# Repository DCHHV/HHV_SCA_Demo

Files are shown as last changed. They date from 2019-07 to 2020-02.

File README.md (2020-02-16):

# DEF CON Hardware Hacking Village Side Channel Attack Demo
This demo focuses on teaching and exploiting a simple timing attack vulnerable set up. It is a hardware device that consists of a PIC12F1572 (Enhanced Mid-range), 4 tactile buttons, LED indicators, an FTDI USB serial interface, and a connection for a logic analyzer (specifically a USBee AX PRO which the HHV has a small stock of). The demo is self-guided, that is, the serial interface provides instructions on each stage of the demo.

## About
The demo consists of 4 stages that become increasingly difficult. Each stage requires the user to identify a valid PIN for that stage. The PIN is a 4 digit, 4 value number; this provides 256 combinations. Due to the low complexity and lack of timeout penalty, brute forcing a PIN for each stage is reasonably possible but highly discouraged since the intent is to learn about side-channel attacks.

There are two LEDs, a red and a green, that flicker when the PIN is being input. The green LED turns on when a button is pressed, and off when it is released. Depending on the stage, once the full PIN is input, the red LED will flash if the pin was incorrect, or the green LED will turn solid for a few seconds if it was correct. The USB serial interface also has a red and green LED to indicate serial activity.

The digits of the PIN are connected to a single analog input of the PIC. Between the switches, a resistor ladder is set up. This allows for a consistent and unique analog voltage value for each digit. The analog input is polled at roughly 8 ms from the PIC (this timing has no bearing on the SCA demo or its vulnerabilities).

The red and green LEDs for the PIN input are connected to a 2x5 0.1" female header. A USBee AX PRO can be directly connected to this input. The LEDs are then connected to D0 and D1 of the logic analyzer. This logic analyzer is compatible with `sigrok`/`pulseview`, it is not a Saleae clone. Any other 3.3 V compatible logic analyzers can be used instead; it was highly convenient to use this pinout as the HHV has a stock of the USBee logic analyzers.

Note that we have observed that some models of Saleae clones actually work better in `pulseview` than the official Logic software. This may be due to a number of reasons, but it was found that in the Logic software both for Windows and Linux, a Saleae clone would often fail to run at 16 MHz. This failure was followed up with a comment to lower the sample rate and try again. Under `pulseview` for both Windows and Linux however, this device performed at the 16 MHz sample rate quite reliably. The USBee AX PRO is not a Saleae clone; this observervation is provided as a reference for using other logic analyzers.

A full breakdown of each stage, how the vulnerability works, step by step instructions, and proper mitigation techniques for this specific setup, are available in `docs/README.md`

## Setup
There is a specific order to the following steps, this is due to `pulseview` recognizing the FTDI device and attempting to utilize it as a logic analyzer interface. Doing this in any other order is possible but it becomes a hassle as `pulseview` tries to consume the USB serial device, even if it is already open in some cases.

1. Connect the USBee AX PRO to the host computer
2. Open `pulseview`. The tool should automatically detect and initialize the logic analyzer, if not, it can be manually set up by scanning for 'fx2lafw' devices. Note that on Linux based systems, there is a separate firmware package for the 'fx2lafw' firmware files.
3. Connect the FTDI USB serial cable (if this is connected before `pulseview` is started, then `pulseview` may try to claim the FTDI device)
4. Open a serial terminal to the just created USB terminal at 9600 baud, 8n1.
5. Press "RESET" button on the HHV SCA Demo board; text should appear on the terminal

## Build your own
All of the PCB sources for EagleCAD are available in the `eagle/` directory. The Gerber files are available in the `eagle/out/` directory and are named directly for use with OSHPark. Simply zip up the files and upload them. The Gerber files are also compatible with pretty much every PCB manufacturer as-is. A full BOM is also in the `eagle/` directory.

The PIC _can_ be programmed via the on-board ICSP header by connecting a PICKit device which supports PIC12F1572. However, we do not recommend connecting directly to this and instead recommend programming the microcontroller out of circuit. Due to conflicting driving signals, there are two marked pads that must be cut for ICSP operation. These must be bridged back together for normal operation.

The `HHV_SCA_Demo-production.hex` file can be directly written to the PIC12F1572.

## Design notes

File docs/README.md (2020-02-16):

# Writeup
**NOTE: This document contains spoilers! While the PIN for each stage is unique every time, this document discusses each stage in detail and how to derive its PIN. Do not proceed if you do not want hints.**

The goal of each stage is to work out the correct PIN. Each stage has a unique 4 digit, 4 value PIN number that is randomly generated each reset of the whole device. As the player progresses through the stages they become increasingly difficult and more subtle.

The following sections describe each stage of the demo; how to exploit the vulnerability, why the vulnerability exists, and eventually how to better mitigate against side-channel attacks. The information here is intended for educational purposes.

Each stage will also output text on the serial terminal. That text is not repeated here as it is simply a description of the stage as well as hinting at how the vulnerability is possible. The text below on each stage provides a more in-depth guide on the stages themselves.

## Stage 0
This stage is meant to be a quick introduction in to how the keyspace can be reduced. Normally, the 4 digit 4 value PIN has 4^4 (256) values. However, the keyspace reduction that is possible is due to the various side-channel vulnerabilities reduces each stage to no more than 4+4+4+4 (16) attempts.

Stage 0 wants a 4 digit PIN, however, it will immediately show a PIN failure if the entered digit is incorrect. For example, if the expected PIN is `0231`:

1. Pressing `0` will result in the green LED turning on when the button is depressed, and the green LED turning off again when the button is released. This means the first digit was correct.
2. Pressing `1` next will also result in the green LED turning on when the button is depressed and back off again when it is released. However, since the second digit of the expected PIN is `2` and we entered a `1`, the red LED will rapidly blink indicating a failure of the PIN input. The device will then go back to waiting for the first PIN digit again.

These two steps indicated to us that `0` is the first digit, and `1` is _NOT_ the second digit. This alone has reduced our keyspace to 0+3+4+4 (11) more attempts as we know the first digit and have eliminated one of the possible second digits. There are 3 more possibilities for the second digit, and it may take 3 attempts to find it if our luck is bad.

This process is repeated until each digit value is found. Once all four correct digits are entered, the green LED will remain solid for roughly 2 seconds indicating success. The next stage is started and text will be output on the terminal to reflect that.

## Stage 1
This stage implements a very common comparison routine to check the input PIN against the expected PIN. This comparison looks at each digit, in order, and compares the input against the expected. If any digit is wrong, the comparison fails immediately. This means that, for each correct digit input, this compare loop takes longer. The exact code implemented is reflected below, it is pulled from `HHV_SCA_Demo.X/main.c`

```C
uint8_t kp_compare()
{
...
	switch(stage) {
	  ...
	  case 1:
		for (i = 0; i < pincnt; i++) {
			if (pin_input[i] != pin[i]) return 0;
		}
	  ...
}
```

When `kp_compare()` is called, and the Demo is currently on Stage 1, the code will iterate through the input PIN and the expected PIN, returning instantly if there is a failure. This creates a difference in execution time when no digits are correct versus the 1st digit is correct, or the first 2 digits are correct, etc.

This is where the LEDs and the logic analyzer connected to them start to become important. Once the 4th digit button is released the green LED turns off to indicate that the button was released. After that, this `kp_compare()` function is called, which takes a variable amount of time to execute depending on how many digits are correct. Once this function is completed, either the green LED turns on to indicate a success or the red LED flashes rapidly to indicate the input PIN was incorrect.

By using the logic analyzer and `pulseview`, this time can be easily measured. The recommended settings are a 12 MHz sample rate, with 500 M Samples. This will result in about 40 seconds of capture time. Additionally, a soft trigger can be set up on the falling edge of D0.

For example, if the expected PIN is `1330`:

1. Start the capture in `pulseview`
2. Enter the PIN `0000`
3. Stop the capture in `pulseview`
4. Zoom in to the very small area between the last rising edge of D1 (the green LED turning off), and the first falling edge of D0 (the red LED turning on to indicate an incorrect input). This area is very small and is only a few hundred microseconds in length!
5. Set up the timing markers on these two edges and note the time between them.
6. Repeat steps 1 through 5 with the PIN `1111`

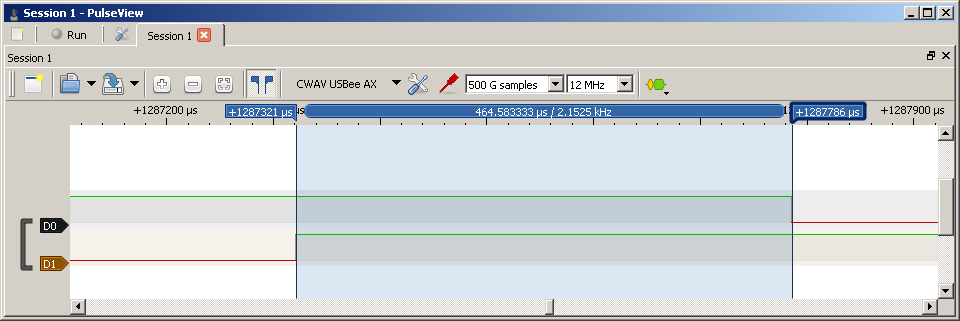
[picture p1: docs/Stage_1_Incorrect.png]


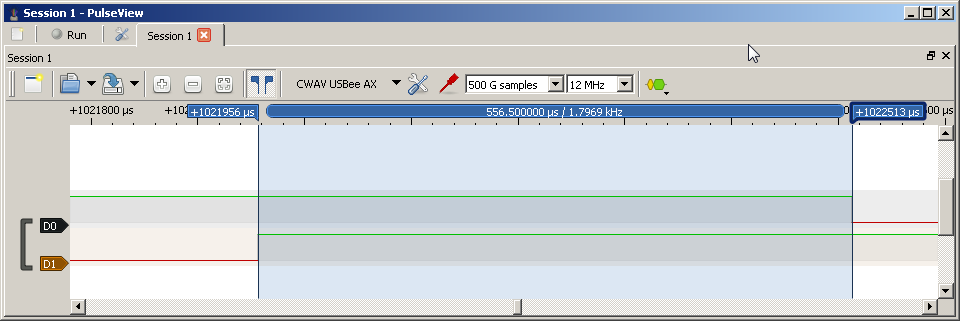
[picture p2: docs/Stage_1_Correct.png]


Notice that the time for a PIN of `1111` takes ~100 μs longer than the PIN of `0000`! This indicates to us that the first digit of the PIN is indeed a `1`. This process is then repeated for each digit position. For example, the next PIN attempt would be `1000` and then `1222` (`1111` was already tested!) and `1333`. One of those will yield a similar timing difference (~100 μs longer) which will indicate the correct 2nd digit; and so on. Note that once the first three digits are resolved, the last one can simply be brute forced in this case. Further testing of the timing will yield no additional results as either the guessed digit was correct (which would complete the stage) or incorrect (which gives no additional information about what the correct digit is).

## Stage 2
Stage 2 adds a little more complexity and subtlety. At the surface it is a naive attempt to mitigate a side-channel attack. Unlike Stage 1, this Stage will not fail the check with a single incorrect digit. Stage 2 will compare each digit of the input and expected PIN and will clear a variable if there is a mismatch. Once all digits are checked, that variable is returned from the function. If the variable is non-zero then the input PIN was correct, if it is zero (that variable was cleared due to an incorrect digit) then any number of digits were incorrect.

The difference here is that when a digit is incorrect an extra step occurs; the clearing of the variable. This clear happens unconditionally, so it happens for every incorrect digit. The exact code used for this is reflected below, it is pulled from `HHV_SCA_Demo.X/main.c`

```C
uint8_t kp_compare()
{
...
	switch(stage) {
	  ...
	  case 2:
		ret = 1;
		for (i = 0; i < pincnt; i++) {
			if (pin_input[i] != pin[i]) {
				ret = 0;
				asm("nop");
			}
		}
	  ...
}
```

_Note: As indicated in the comments in `main.c`, the PIC architecture makes this specific scenario difficult to achieve. Without the `nop` instruction, the emitted code by the xc8 compiler is correctly balanced; it takes the same number of instructions for a matching and non-matching digit. The `nop` forces this extra instruction in this case. Other architectures and/or compilers optimized for execution speed rather than code size may output unbalanced code around this if() statement without the additional `nop` instruction. This highlights that not all code is perfectly portable. This code without the `nop` instruction might be balanced on this PIC, but when moved to a different microcontroller with a different compiler, that code may open up a vulnerability to SCA exploitation._

The next important bit of information involves the PIC itself. The PIC12F1572 that is handling all of this, is running at a clock speed of 1 MHz. This specific series of devices has 4 clocks per every instruction executed. This means that the instructions are executed at a rate of 250 kHz, or one instruction every 4 μs. Note that some instructions take multiple instruction cycles; but for the purpose of this stage each path has a 1 instruction difference.

To bring it all together, for every incorrect digit of the input PIN, the PIC runs one additional instruction compared to if the digit were correct. Every incorrect digit results in a 4 μs increase in execution time. When looking at the LEDs in the logic analyzer, the difference between the last rising edge of D1 and the first falling edge of D0 increases 4 μs for each digit that is incorrect. This specific implementation will essentially tell you how many digits you have correct or incorrect, but not which ones. It can be compared to a game of [Mastermind (external link)](https://en.wikipedia.org/wiki/Mastermind_(board_game))

For example, with a PIN of \[REDACTED\]

1. Start capture in `pulseview`
2. Enter PIN `0000`
3. Stop capture in `pulseview`
4. Zoom in to the very small area between the last rising edge of D1 (the green LED turning off), and the first falling edge of D0 (the red LED turning on to indicate an incorrect input). This area is very small and is only a few hundred microseconds in length!
5. Set up the timing markers on these two edges and note the time between them.
6. Repeat steps 1 through 5 with the PIN `1111`, `2222`, and `3333`
7. Some logic and reasoning needs to be used here. With the above PINs, we gathered the following details:

   `0000` Took 841 μs
   `1111` Took 841 μs
   `2222` Took 837 μs
   `3333` Took 845 μs

   Note that `3333` took the longest, with at least two more incorrect digits than `2222`. This tells us that there are likely multiple `2`s in the final PIN, and likely no `3`s. But in order for us to continue, we need to eliminate one of the variables by resolving one of the digits. Let's repeat steps 1 through 5 with the following combinations.

   `2000` Took 841 μs
   `0200` Took 845 μs

   Stopping there, we see the difference between `0000` (see above) and `0200` is that `0200` is one instruction longer, meaning the `0` in the second place was correct, and replacing it with a `2` made that digit incorrect. We have just found our first digit, `x0xx`

   `0020` Took 837 μs

    Stopping there again, we see that changing the third place digit from a `0` to a `2` caused it to decrease in time and therefore meaning it is correct. We have now found our second digit, `x02x`

   `0022` Took 833 μs

   This is our last needed test. Moving the fourth digit from a `0` to a `2` yet again decreased the comparison time. This indicates that 2 is indeed the final digit. We have found three of the digits, `x022`.
   
   But actually, we already know the final digit! Above, it was noted that `0000` and `1111` took the same amount of time. This means that both of them have the same number of correct and incorrect digits. If `x022` is the correct PIN, then the PINs `0000` and `1111` have at least the final two digits incorrect meaning that each of them also have a correct and incorrect digit. If the final PIN is `x022` then the correct digit in `1111` would be the first place digit, meaning the full PIN is `1022`.

It is important to note that this evaluation process is not the same every time. There are seeds where the first four samples above will all take the same amount of time! With that, you can know that each of them has a single correct digit, and the final PIN has no repeating values. A lot of side-channel attacks require reasoning and deduction in order to understand how the whole system works together. Also note that as in Stage 1, it would be possible to brute force the missing first digit. We just happened to have enough information already in order to work out what it was.

## Stage 3
This stage, to the best of my abilities, is immune from a side-channel timing attack. It is difficult to prove something as "secure" unfortunately. But, the comparison function for this stage is hand-tuned assembly code that has been shown to be the same amount of instructions for each matching or non-matching PIN digit. This stage builds on the concept of the previous Stage. Each digit of the input PIN and expected PIN are compared one by one. For each correct digit the next iteration of the loop is run. For each incorrect digit a variable is incremented. However the paths for correct and incorrect digits take the same amount of instruction cycles. Meaning that no matter how many digits are correct or incorrect, the same amount of time elapses in the comparison function, and no data is leaked out about the expected PIN. After the comparison loop, the variable's value is examined. If the variable is `0`, then none of the digits were incorrect. If the variable is any other value, then some number of digits were incorrect.

Additionally, interrupts are disabled before the call to `kp_compare()` (this happens on every stage anyway). 

This takes place over two functions, `kp_compare()` as all of the other Stages have used, which makes a call to an assembly function `_proper_compare`. The important parts of these are outlined below, taken directly from `HHV_SCA_Demo.X/main.c` and `HHV_SCA_Demo.X/proper_compare.s`

```C
uint8_t kp_compare()
{
...
	switch(stage) {
	  ...
	  case 3:
		if (proper_compare() != 0) ret = 0;
		break;
	  ...
}
```
```
_proper_compare:

    CLRF    _cmp
    MOVLW   3;
    MOVWF   _loop;

stage_3_loop:
    /* Load the address of pin_input+3 in to FSR0 */
    MOVLW   low _pin_input
    ADDWF   _loop, W
    MOVWF   FSR0L
    CLRF    FSR0H

    /* Load the address of pin+3 in to FS10 */
    MOVLW   low _pin
    ADDWF   _loop, W
    MOVWF   FSR1L
    CLRF    FSR1H

    /* Compare the two values via XOR. Z flag is set when they are equal */
    MOVF    INDF0, W;
    XORWF   INDF1, W;

    /* Start critical section */
    BTFSS   STATUS, 2;          // 2 cycles if Zero is set, 1 if not. Bit 2 is Z
    INCF    _cmp, F;            // 1 cycle.
    /* End critical section */

check_loop:                     //From BTFSS, both paths take 2 cycles to here.
    CLRW;
    XORWF   _loop, W;
    BTFSC   STATUS, 2;          //2 cycles if true, 1 if false. Bit 2 is Z
    GOTO    end_loop;

    DECF    _loop, F;
    GOTO    stage_3_loop;
...
```

Despite all of that however, Stage 3 is weak and the PIN can be derived through other means.

When starting up the demo, the intro screen on the terminal talks about setup and other background information and asks you to press "Enter" to continue. In the background, a timer is running from the moment the PIC is released from internal reset. It is when "Enter" is pressed on the keyboard that this 8-bit timer is sampled and used as a seed value for all of the expected PINs. This seed is also printed in such a way that it is hidden on most serial terminals.

From this seed, a PRNG using a Galois Linear Feedback Shift Register is used to transform it to the next step. The first transformation is used for Stage 0, it is transformed again for Stage 1, etc. Each stage only transforms the number one time. However, since the seed and each transformation of the PRNG is only 8-bits, it is a fairly weak PRNG that allows it to be easily discovered.

The PRNG transformation happens with the function below, taken directly from `HHV_SCA_Demo.X/main.c`

```C
void generate_pin(void)
{
	uint8_t seed_copy, i;
	seed = seed >> 1;
	if (CARRY) seed ^= 0xB8;
	seed_copy = seed;
	for (i = 3; i != 0; i--) {
		pin[i] = seed_copy & 0x3;
		seed_copy >>= 2;
	}
	pin[0] = seed_copy & 0x3;
}
```

Each transformation shifts the value one to the right. If the least significant bit before the shift was a `1`, then the whole value is XORed against the value 0xB8. Then, each pair of bits is used to represent 1 digit. The first digit is represented by seed bits 7:6, the second is seed bits 5:4, etc. Since each pair of bits can represent a value of 0 through 3, they directly correlate to the values that can be input.

Often it is possible to gather the seed and each PIN from all prior stages and reverse engineer how the PRNG transforms for each stage. However it is also possible that multiple run-throughs of the stages are necessary to gather all of the information. Having a seed that has both the right shift by itself, as well as the XOR operation occur throughout the transformations will allow one to see exactly what is going on. There are some seeds that will only result in a right shift for every transformation through the Stages, and other seeds that will only result in the shift and XOR for every transformation through the Stages. It is these seeds that will require multiple run-throughs of the Demo.

Once the transformation process is understood however, it is possible to see the seed and derive every single PIN for all 4 Stages.

## Mitigations
In this application, only time was used as a side-channel attack vector. There are many other sections of side-channel data that can be used in similar attacks. Some of the other common ones are power monitoring, and electromagnetic radiation monitoring. All of the Stages of this demo may be susceptible to other types of attacks. If you are able to demonstrate another type of analysis on this device, we would love to hear about it!

The process used in Stage 3 is likely the most robust. However, it does depend on a completely deterministic processor and firmware so that each code path can be properly tuned. And since the interrupts are disabled during the compare, nothing can be used to stall or interfere with the compare functions. Systems with pipelines and/or other optimizations to speed up execution at the cost of determinism may not be able to implement such a simple system without a performance hit.

To the best of my knowledge, there are currently no blanket rules or guidelines to follow to reduce the attack surface and mitigate any kind of side-channel attacks. Each application must determine the best security and best course of action to accomplish this.

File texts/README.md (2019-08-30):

# Texts
Text strings used in the Demo. See `tools/README.md`, `tools/string_packer.c`, and `HHV_SCA_Demo.X/main.c` for information on how these texts are formatted and used.

The `./build-asm.sh` script is provided as a helper function to quickly rebuild the `strings.s` source file used during final assembly of the project

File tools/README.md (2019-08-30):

# Tools

## Building
Simply run `make` to build all of the tools here. They are simple C programs that rely on no external libraries.

## pin\_predictor
For testing purposes, the `pin_predictor` tool can be used to output every combination of every possible seed. Useful for jumping through to specific stages, verifying the PRNG transformation works as expected, etc.

It is just run with `./pin_predictor` and will output the 4 PIN associated with each stage for every seed from 0x00 through 0xFF. Note that seed 0x00 is invalid during runtime of the Demo itself. All four of the stages have the same pin of `0000`.

## string\_packer
In order to fit all of the text in to the PIC that is in there the characters all needed to be packed two to a single word. The PIC12F1572 uses 14-bit instruction words. With 7-bit ASCII this allows for storing two characters in each instruction word. The full 14-bit value of the instruction word can be arbitrarily loaded with assembly directives. However, when using strings in C, they are packed as a single character per word.

This tool was created to take a listing of plaintext via stdin (all of which are maintained in the `texts/` directory) and output very specifically formatted text that can be added to the project as an assembly include. The expected input format is:

```
<name_of_array>
Text to put in.\r\n
...
```

And the tool will output via stdout:

```
PSECT strings,class=CODE,local,delta=2
GLOBAL _<name_of_array>
_<name_of_array>:
DW      0x... ; "XX"
...
```

The \<name\_of\_array\> names are critical as they must align with expected names in the C sources.

The `string_packer` tool will accept the most common escape sequences, `\n`, `\r`, `\t`, and `\\`. If an invalid escape is used, the program will fail an spit out the byte that it tripped on.

In the assembly output, the two represented characters will be appended to the line as a comment, for example:

`DW      0x2A68 ; "Th"`

Since all strings must end on a `\0` byte, `string_packer` adds either a single 0x00 to the lower byte of an instruction word, or a full instruction word of 0x0000. Adding a `\0` at the end of the plaintext is not needed and will cause errors. Example output of this process:

```
...
DW      0x2E80 ; "]\0"
...
DW      0x0000 ; "\0\0"
...
```

The firmware on the PIC has a decode function to be able to print these packed strings. Since the `string_packer` added `\0` bytes at the end of each string, the print function in the PIC will read byte by byte until it encounters a `\0` byte like a normal string print function.

The `string_packer` tool can be run with `./string_packer < textfile.txt >> strings.s`. The order of the text files to be processed does not matter, but it is most logical to keep them in order that they are printed.

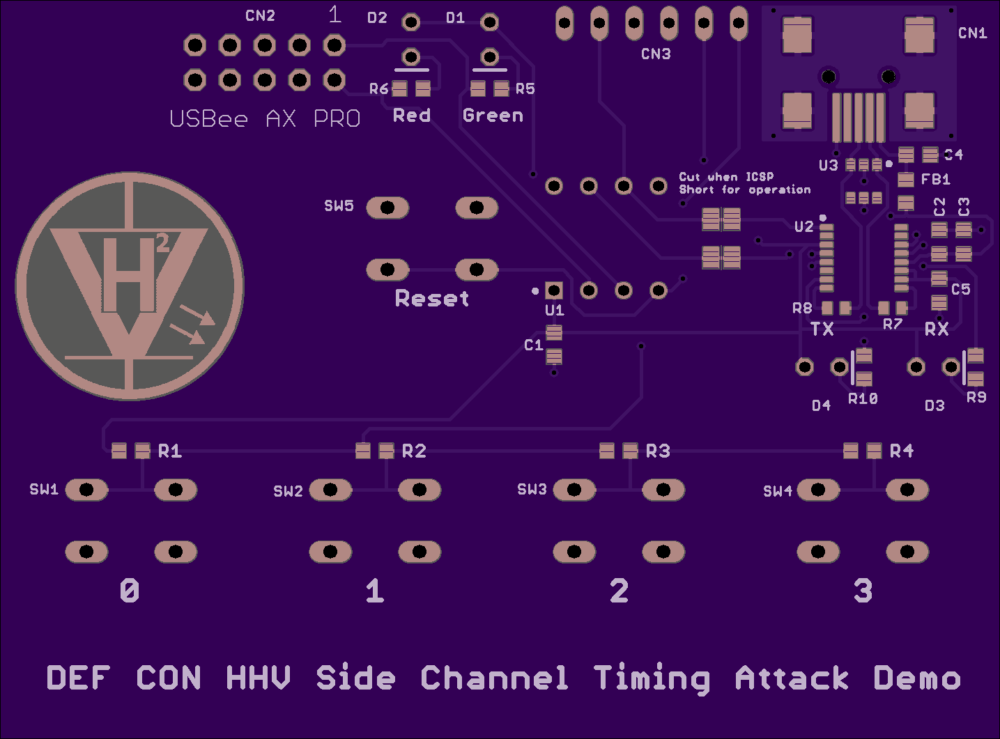
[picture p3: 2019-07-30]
docs/OSHPark-top.png

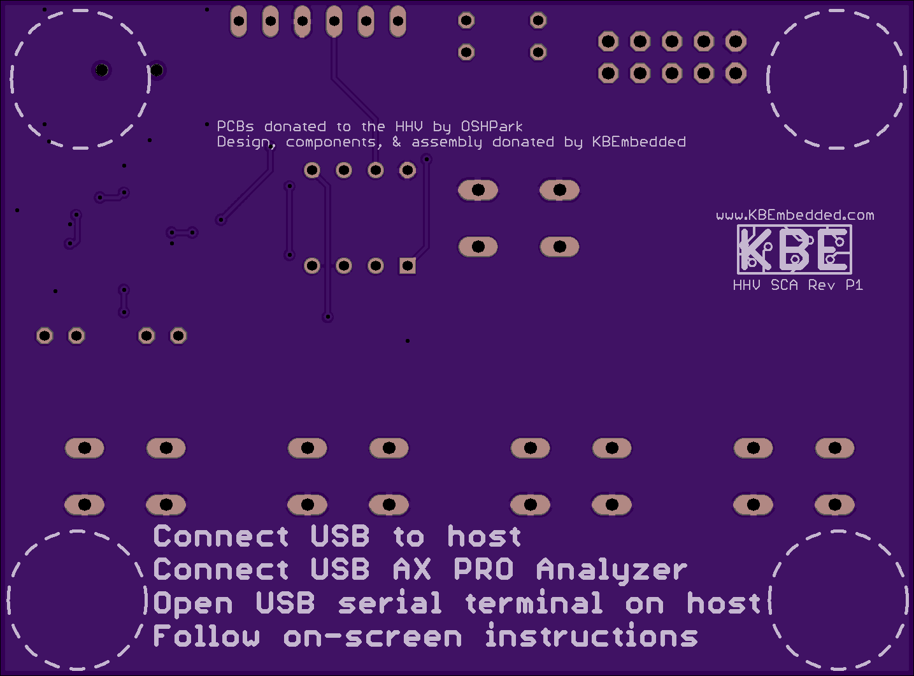
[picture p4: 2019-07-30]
docs/OSHPark-bottom.png

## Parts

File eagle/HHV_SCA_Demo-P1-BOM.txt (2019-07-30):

Qty Value        Device       Package      Parts                   Description                
1                R-EU_R0603   R0603        FB1                     FERRITE BEAD
2   27           R-US_R0402   R0402        R7, R8                  RESISTOR
4   100          R-US_R0603   R0603        R5, R6, R9, R10         RESISTOR
4   10k          R-US_R0603   R0603        R1, R2, R3, R4          RESISTOR
1   10nF         C-EUC0603K   C0603K       C4                      CAPACITOR
3   .1uF         C-EUC0603K   C0603K       C1, C2, C5              CAPACITOR
1   4.7uF        C-EUC0603K   C0603K       C3                      CAPACITOR
1   AOZ8105CI    AOZ8105CI    SOT23-6L     U3                      TVS
1                FE06-1       FE06         CN3                     FEMALE HEADER              
1                MA05-2       MA05-2       CN2                     PIN HEADER                 
1   FT230XS      FT230XS      SSOP16       U2                      USB to BASIC UART IC       
1   MINIUSB-SMD  MINIUSB-SMD  MINIUSB-SMD  CN1                     EDAC 690-005-299-043       
1   PIC12F1572   PIC12F1571   DIL8         U1                      PIC12F1571/2               
2   RED          LED3MM       LED3MM       D2, D3                  LED                        
2   GRN          LED3MM       LED3MM       D1, D4                  LED                        
5                10-XX        B3F-10XX     SW1, SW2, SW3, SW4, SW5 OMRON SWITCH

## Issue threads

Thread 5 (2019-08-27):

Text: Change recommended settings to 12 MHz @ 500 M samples

kbembedded, 2019-08-27:
Some of the USBee AX PROs have issues running at 16 MHz. It seems to be pretty dependent on the computer, the device, and even the cable. In testing, 12 MHz has been very reliable in all situations.

The 12 MHz @ 500 M samples takes about 500 MB of RAM

kbembedded, 2020-02-16:
Fixed in 0e4efee7c25362291c2eec0b00dc4f5ef78d1afe

Closed 2020-02-16.

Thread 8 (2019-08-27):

Rewrite Stage 2 code to be correct no matter the compiler

kbembedded, 2019-08-27:
Currently, with xc8 2.05 compiler, it accidentally optimizes the code to have balanced code paths for both correct and incorrect digits.

This likely needs to move to an assembly routine so that it can be properly tuned so that is intentionally unbalanced and agnostic of any future compiler changes.

kbembedded, 2020-02-16:
Not easily possible with PIC architecture without going out of the way to write weird code. Left the asm `nop` in place in C and added documentation about it.

Closed 2020-02-16.

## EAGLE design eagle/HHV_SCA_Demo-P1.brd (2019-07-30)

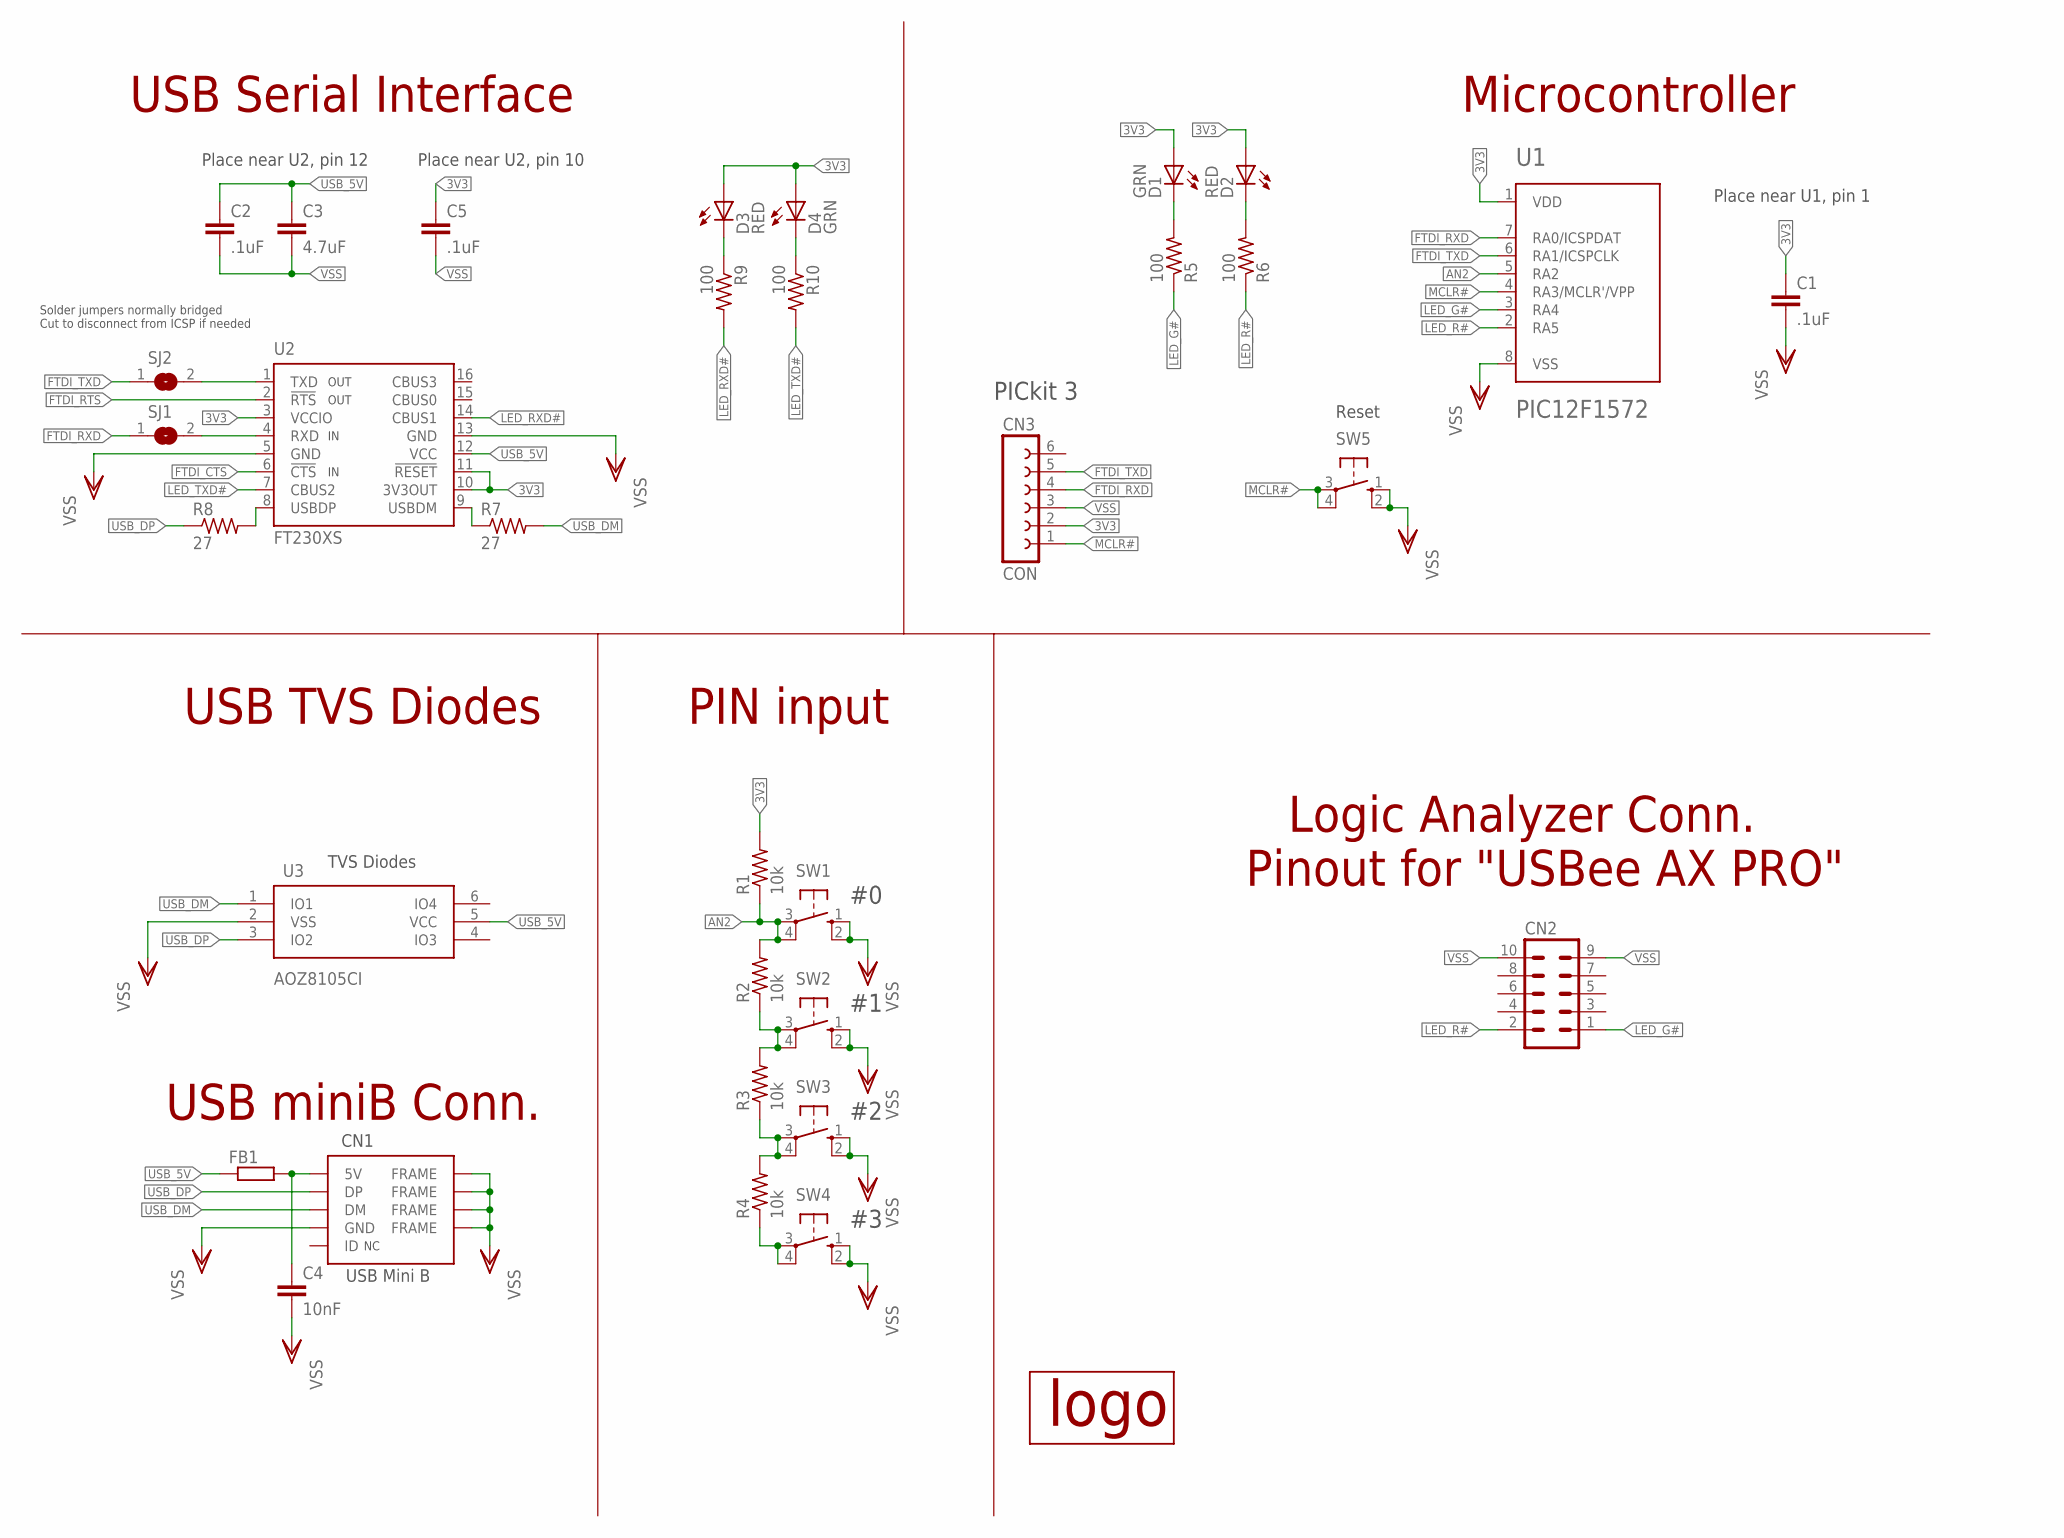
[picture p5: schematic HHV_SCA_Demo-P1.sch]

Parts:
C1, C2, C5: .1uF; C0603K
C3: 4.7uF; C0603K
C4: 10nF; C0603K
CN1: MINIUSB-SMD
CN2: MA05-2
CN3: CON; FE06
D1, D4: GRN; LED3MM
D2, D3: RED; LED3MM
FB1: R-EU_R0603; R0603
R1, R2, R3, R4: 10k; R0603
R5, R6, R9, R10: 100; R0603
R7, R8: 27; R0402
SJ1, SJ2: SJ
SW1, SW2, SW3, SW4, SW5: 10-XX; B3F-10XX
U1: PIC12F1572; DIL8
U2: FT230XS; SSOP16
U3: AOZ8105CI; SOT23-6L
U$1: KBELOGO-SILK

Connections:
3V3: C1.1, C5.1, CN3.2, D1.A, D2.A, D3.A, D4.A, R1.2, U1.1 (VDD), U2.3 (VCCIO), U2.10 (3V3OUT), U2.11 (!RESET)
AN2: R1.1, R2.2, SW1.3, SW1.4 (P1), U1.5 (RA2)
FTDI_CTS: U2.6 (!CTS)
FTDI_RTS: U2.2 (!RTS)
FTDI_RXD: CN3.4, SJ1.1, U1.7 (RA0/ICSPDAT)
FTDI_TXD: CN3.5, SJ2.1, U1.6 (RA1/ICSPCLK)
LED_G#: CN2.1, R5.1, U1.3 (RA4)
LED_R#: CN2.2, R6.1, U1.2 (RA5)
LED_RXD#: R9.2, U2.14 (CBUS1)
LED_TXD#: R10.2, U2.7 (CBUS2)
MCLR#: CN3.1, SW5.3, SW5.4 (P1), U1.4 (RA3/MCLR'/VPP)
unnamed: R4.1, SW4.3, SW4.4 (P1)
unnamed: R3.1, R4.2, SW3.3, SW3.4 (P1)
unnamed: D2.K (C), R6.2
unnamed: R7.1, U2.9 (USBDM)
unnamed: R2.1, R3.2, SW2.3, SW2.4 (P1)
unnamed: R8.2, U2.8 (USBDP)
unnamed: D1.K (C), R5.2
unnamed: D3.K (C), R9.1
unnamed: C4.1, CN1.5V, FB1.2
unnamed: D4.K (C), R10.1
unnamed: SJ2.2, U2.1 (TXD)
unnamed: SJ1.2, U2.4 (RXD)
USB_5V: C2.1, C3.1, FB1.1, U2.12 (VCC), U3.5 (VCC)
USB_DM: CN1.USB_DM (DM), R7.2, U3.1 (IO1)
USB_DP: CN1.USB_DP (DP), R8.1, U3.3 (IO2)
VSS: C1.2, C2.2, C3.2, C4.2, C5.2, CN1.GND@0 (FRAME), CN1.GND@1 (FRAME), CN1.GND@2 (FRAME), CN1.GND@3 (FRAME), CN1.VSS (GND), CN2.9, CN2.10, CN3.3, SW1.1 (S), SW1.2 (S1), SW2.1 (S), SW2.2 (S1), SW3.1 (S), SW3.2 (S1), SW4.1 (S), SW4.2 (S1), SW5.1 (S), SW5.2 (S1), U1.8 (VSS), U2.5 (GND), U2.13 (GND), U3.2 (VSS)

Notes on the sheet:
OUT
Place near U2, pin 12
TVS Diodes
Place near U2, pin 10
CN1
USB Mini B
PICkit 3
Place near U1, pin 1
USB Serial Interface
USB TVS Diodes
USB miniB Conn.
Microcontroller
Reset
PIN input
Logic Analyzer Conn. Pinout for "USBee AX PRO"
Solder jumpers normally bridged Cut to disconnect from ICSP if needed

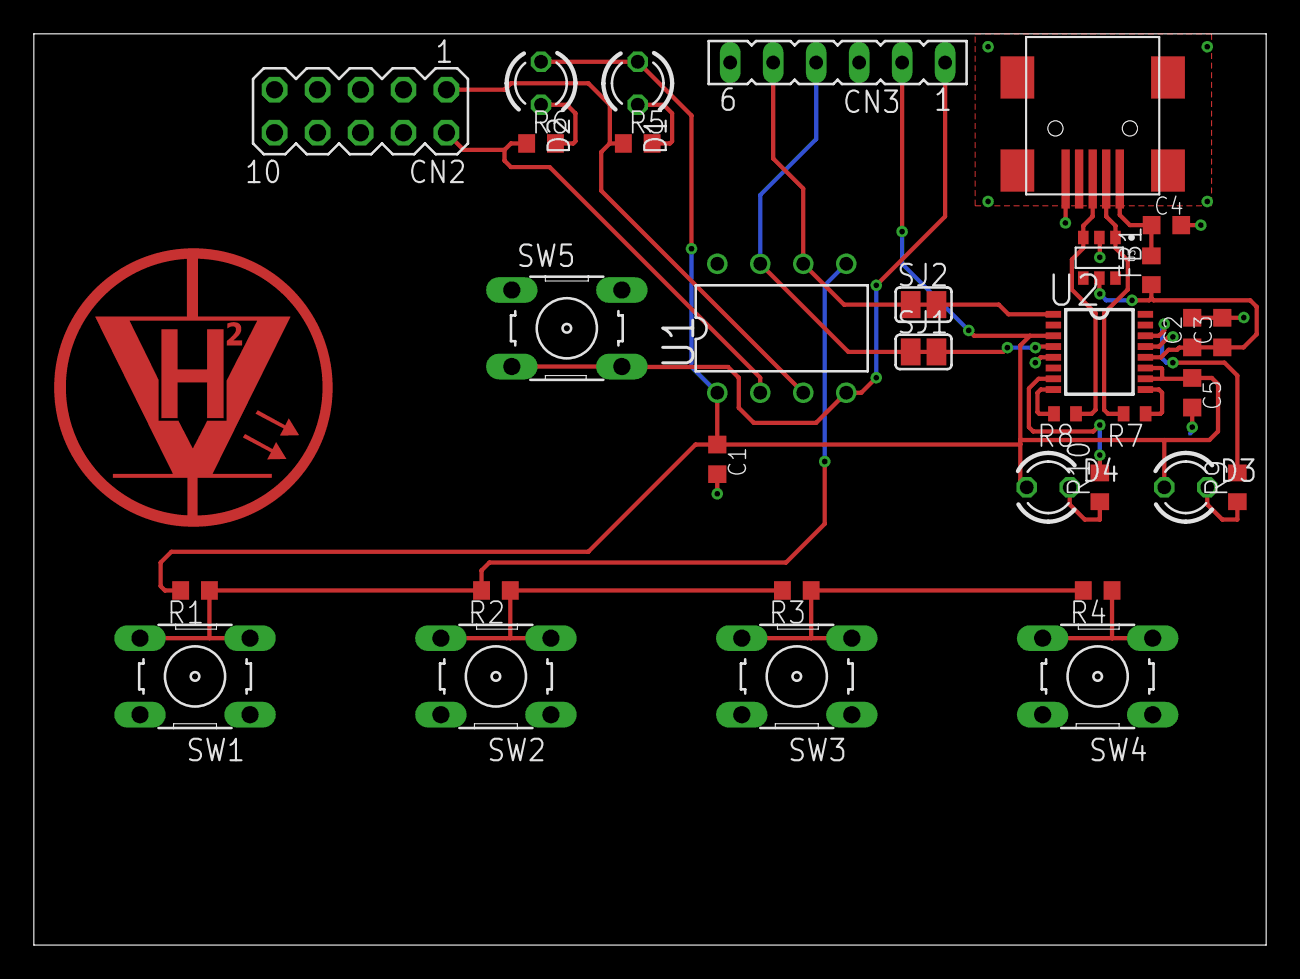
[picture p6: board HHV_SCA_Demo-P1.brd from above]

Board: 2 copper layers, 72.8 x 53.8 mm, 34 parts (1 on the bottom side), 25 nets.

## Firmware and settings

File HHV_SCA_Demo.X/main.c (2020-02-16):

/* SPDX-License-Identifier: BSD-2-Clause */
/* Copyright (c) 2019 KBEmbedded and DEF CON Hardware Hacking Village */

/*
 * Basic pinmap reference
 * RA0: TXD
 * RA1: RXD
 * RA2: Analog button input
 * RA3: Unused
 * RA4: Green LED#
 * RA5: Red LED#
 */

#include <xc.h>

//#define ECHO_UART             // Uncomment to enable echo of recv'ed chars

#define _XTAL_FREQ 1000000   // Oscillator frequency.

#pragma config FOSC = INTOSC  // INTOSC oscillator: I/O function on CLKIN pin.
#pragma config WDTE = OFF     // Watchdog Timer disable.
#pragma config PWRTE = OFF    // Power-up Timer enbable.
#pragma config MCLRE = ON     // MCLR/VPP pin function is MCLR.
#pragma config CP = OFF       // Program memory code protection disabled.
#pragma config BOREN = ON     // Brown-out Reset enabled.
#pragma config CLKOUTEN = OFF // CLKOUT function is disabled; I/O or oscillator function on the CLKOUT pin.
#pragma config WRT = OFF      // Flash Memory Write protection off.
#pragma config STVREN = ON    // Stack Overflow or Underflow will cause a Reset.
#pragma config BORV = LO      // Brown-out Reset Voltage (Vbor), low trip point selected.
#pragma config LVP = OFF      // High-voltage on MCLR/VPP must be used for programming.

#include <stddef.h>
#include <stdio.h>
#include <stdint.h>
#include <stdlib.h>
#include <string.h>

extern uint8_t proper_compare(void);

/* Make most of the important things global. Saves program space not having to
 * push/pop values for function calls.
 * In some situations, all global could be worse due to bank switching code.
 * However this code has been tested as globals vs function arguments, and it
 * was found that globals can save >60 words compared to function args.
 */
volatile uint8_t uart_byte;
volatile uint8_t adc_byte;
volatile bit adc_flag;
volatile bit uart_flag;
volatile bit blink_flag;
volatile bit newline_flag;
bit did_something = 0;  //Global so it is optimized with other bits
unsigned char cmdstring[9] = {0};

uint8_t pincnt;
uint8_t stage;
uint8_t seed;

/* These are put in common RAM. This helps reduce programming strain for the
 * stage 3 section with assembly. No worrying about banking for these since
 * 0x70-0x7F are available in any bank.
 * Probably not the most efficient, but, makes the ASM for the compare easier.
 */

volatile uint8_t pin_input[4] __at(0x70);
volatile uint8_t pin[4] __at(0x74);
volatile uint8_t loop __at(0x78);
volatile uint8_t cmp __at(0x79);

#define LED_G 4
#define LED_R 5

extern const char intro_text[];
extern const char stage_0_text[];
extern const char stage_1_text[];
extern const char stage_2_text[];
extern const char stage_3_text[];
extern const char completed_text[];

/* For some reason, this array cannot have its members defined at compile time
 * without a call to "puts(stage_text[<value>])" SOMEWHERE in the source. The
 * compromise
 */
const char *stage_text[5];

void init_pic() {
  OSCCON = 0b01011010; // 1 Mhz internal oscillator. 250khz instruction time.
  ANSELA = 0b00000100; // Analog enable on RA2 for button input
  TRISAbits.TRISA2 = 1;
  
  /* LEDs as outputs, active low */
  PORTAbits.RA4 = 1;
  PORTAbits.RA5 = 1;
  TRISAbits.TRISA4 = 0;
  TRISAbits.TRISA5 = 0;
}

void init_uart() {
  TRISAbits.TRISA1 = 1; // UART RX pin an input.
  TRISAbits.TRISA0 = 0; // UART TX pin an output.

  // 9600 bps, 1 MHz oscillator.
  SPBRGH = 0x00;
  SPBRGL = 0x19;

  // 16-bit Baud Rate Generator
  BAUDCONbits.BRG16 = 1;

  TXSTAbits.TXEN = 1; // Transmit enabled.
  TXSTAbits.SYNC = 0; // Enable asynchronous mode.
  TXSTAbits.BRGH = 1; // High speed.

  RCSTAbits.SPEN = 1; // Enable serial port.

}

void init_adc(void) {
    /* ANSEL/TRIS already set by init_pic() */
    
    /* Set channel selection, AN2 */
    ADCON0bits.CHS = 0b00010;
    
    /* Set VREF to VDD */
    ADCON1bits.ADPREF = 0;
    
    /* Set conversion clock, Fosc/64, ~4 us conversion time */
    ADCON1bits.ADCS = 0b100;
    
    /* 10-bit left-justified */
    ADCON1bits.ADFM = 0;
    
    /* Enable ADC */
    ADCON0bits.ADON = 1;
    
    /* Enable ADC conversion interrupt */
    PIR1bits.ADIF = 0;
    PIE1bits.ADIE = 1;
    
    /* Enable timed conversion, ~10ms, from Timer0 */
    ADCON2bits.TRIGSEL = 0b0011;
    
    adc_flag = 0;
}

/* Set up Timer0 with 1:8 prescaler
 * At 1 MHz, this is roughly 8.2 ms, a close enough timing for ADC
 */
void init_timer0(void) 
{
    TMR0 = 0;
    OPTION_REGbits.PSA = 0;
    OPTION_REGbits.PS = 0b010;
    OPTION_REGbits.TMR0CS = 0;
}

void putch(unsigned char byte) {
  // Wait until no char is being held for transmission in the TXREG.
  while (!PIR1bits.TXIF) {
    continue;
  }
  // Write the byte to the transmission register.
  TXREG = byte;
}

/* Main interrupt handler. Only interrupts we have are from UART RX and ADC.
 * ADC acquisition is set up on a timer. Bitflags are used to keep track of
 * states. The ISR only ever sets these flags, the rest of the code will only
 * clear them.
 */
void interrupt interrupt_handler() {
  if (PIR1bits.RCIF && PIE1bits.RCIE) {
    // EUSART receiver enabled and unread char in receive FIFO.
    if (RCSTAbits.OERR) {
      // Overrun error.
      RCSTAbits.CREN = 0;          // Clear the OERR flag.
      uart_byte = RCREG; // Clear any framing error.
      RCSTAbits.CREN = 1;
    } else {
      uart_byte = RCREG;
      if(uart_byte == '\r') newline_flag = 1;
      else uart_flag = 1;
    }
  }
  
  /* ADC, PIR1bits.ADIF must be manually cleared */
  if (PIR1bits.ADIF && PIE1bits.ADIE) {
      PIR1bits.ADIF = 0;
      adc_byte = ADRESH;
      adc_flag = 1;
  }
}

void led_toggle(uint8_t led) {
    LATA ^= (uint8_t)(1 << led);
}

void led_blink(uint8_t led) {
    led_toggle(led);
    __delay_ms(50);
    led_toggle(led);
}

void led_flicker(uint8_t led)
{
    uint8_t i;
    
    for (i = 10; i != 0; i--) {
        led_blink(led);
        __delay_ms(50);
    }
}

/* This function is a "bottom half" of the ADC. In it, the value of the last
 * ADC conversion is parsed. The buttons on the device are set up with a
 * resistor ladder; each button press returning roughly half the value of the
 * next one up. The ADC will be at max voltage when no button press, and ground
 * when the leftmost button is pressed. This is parsed to a sane value, 0 - 3,
 * matching each button value. A value of 255 means that no buttons are being
 * pushed.
 * 
 * This function requires two consecutive reads to match in terms of value.
 * Once two matching readings are taken, the function ignores all other input
 * until all buttons are released for a sample. At which time the return value
 * of this function is 1 to indicate a valid read. All other returns of this
 * function is 0.
 */
uint8_t adc_parse(void) {
    static bit repeated;
    static bit valid_press;
    uint8_t ret = 0;
    uint8_t str_val;
    
    /* This can waste time by setting str_val multiple times, but it saves some
     * code space vs ranged if statements or else if's. This is outside of the
     * critical time section also. */
    str_val = 0;
    if (adc_byte > 0x3F) str_val = 1;
    if (adc_byte > 0x94) str_val = 2;
    if (adc_byte > 0xB3) str_val = 3;
    if (adc_byte > 0xE4) str_val = 255; //Released button
    
    if (repeated && (pin_input[pincnt] == str_val)) {
        repeated = 0;
        valid_press = 1;
        led_toggle(LED_G);        
    } 
    
    if (!valid_press && (str_val != 255)) {
        pin_input[pincnt] = str_val;
        repeated = 1;
    }
    
    if (valid_press && str_val == 255) {
        valid_press = 0;
        ret = 1;
        led_toggle(LED_G);
    }
    
    return ret;
}

/* This function is used to compare the input PIN to the expected PIN. The
 * pin_input variable is the last input complete pin, while the pin variable
 * is the expected PIN.
 * 
 * Each stage is represented, and each stage performs a different compare
 * function. See the switch statement below for more information
 * 
 * Returns a 1 if the strings match, a 0 otherwise.
 */
uint8_t kp_compare()
{
    uint8_t i;
    uint8_t ret = 1;
    
    switch(stage) {
        /* Stage 0 is odd because each button input is tested as it comes in.
         * This never happens in the real world and is stupid. But it is meant
         * to exaggerate and show how the next stage is just as naive.
         */
        case 0:
            if (pin_input[pincnt-1] != pin[pincnt-1]) ret = 0;
            break;

        /* Stage 1 is a common naive password compare. Starting at one end, it
         * compares each place of the PIN with the expected value. At the first
         * incorrect value, the function returns.
         *
         * This allows one to identify the pin, place by place, in less than
         * 4+4+4+4 guesses.
         */
        case 1:
            for (i = 0; i < pincnt; i++) {
                if (pin_input[i] != pin[i]) return 0;
            }
            break;

        /* Stage 2 is meant to be a naive fix to the above problem. A value is
         * set at the start of the loop. In this loop, every digit of the PIN
         * is compared against what is expected. If the digit is incorrect, then
         * the value is cleared and the PIN is incorrect.
         *
         * While this does compare each digit, unlike above, the time is still
         * different for a matching and non-matching digit. This time difference
         * allows one to narrow in on how many correct and incorrect
         * digits there are.
         *
         * Note that this architecture makes this specific scenario actually
         * kind of difficult. Compilers optimized for speed with direct compare
         * and jump instructions could opt to compare and jump if false, or
         * compare, execute the next instruction 'ret = 0', and then jump. The
         * idea here is that the paths of the if() statement are different
         * lengths.
         *
         * A nop instruction was added below in order to ensure this function
         * is broken in the intended way. The 'ret = 0' instruction is basically
         * free with the way the PIC tests bit set/clr and skips instructions.
         * Which causes the true and false paths to be equal in length.
         * This behavior can be seen in the proper_compare() function.
         */
        case 2:
            for (i = 0; i < pincnt; i++) {
                if (pin_input[i] != pin[i]) {
                    ret = 0;
                    asm("nop");
                }
            }
            break;

        /* Stage 3 is a correct way to do PIN compare. It is hand tuned ASM
         * (see the function in compare.s) that checks every place, and whether
         * the digit matches or not, takes the same amount of time.
         *
         * The assembly will add 1 to a variable for every non-matching place.
         * At the end, a single compare against 0 is used. If that value was 0,
         * it means all four places were correct. If it is nonzero, it means
         * not all four places were correct.
         *
         * Using this method and carefully understanding the critical time
         * sections, it is possible to create a routine that will leak no info
         * about how many digits were correct or incorrect.
         *
         * Stage 3, while implemented correctly, is readily defeated due to the
         * poor PRNG that drives the PIN generation.
         */
        case 3:
            if (proper_compare() != 0) ret = 0;
            break;
                        
        default:
            break;
    }
    
    return ret;
}

/* This function is essentially a Galois LFSR for pseudorandom number generation
 * This is like any other basic PRNG, in that once the seed or any value that
 * comes from it is known, as well as how the PRNG steps happen, the entire
 * stream can then be predicted.
 * 
 * The seed is generated at the start based on a timer and human interaction.
 * This delay allows for a somewhat random seed, however it is only 8-bits.
 * 
 * The PIN of each stage is derived directly from the current PRNG value. The
 * 8-bit value is broken in to 4x 2-bit quantities, the PIN digit value is the
 * value of each 2-bit quantity. Hence, a direct mapping of 0-3.
 * 
 * This function directly writes the expected PIN value to its array each call.
 */
void generate_pin(void)
{
    uint8_t seed_copy, i;
    seed = seed >> 1;
    if (CARRY) seed ^= 0xB8;
    seed_copy = seed;
    for (i = 3; i != 0; i--) {
        pin[i] = seed_copy & 0x3;
        seed_copy >>= 2;
    }
    pin[0] = seed_copy & 0x3;
}

/* This function reads const char arrays from program flash. The program flash
 * of this PIC12F1572 uses 14-bit words. Two 7-bit ASCII characters can fit in
 * each word.
 * 
 * The high byte is the first character, the low byte is the second. It is
 * guaranteed that at the end of each array, both high and low bytes will be
 * NULL, or low byte will be NULL.
 * 
 * Due to the limitation of this specific PIC, the indirect registers cannot be
 * used to read all 14-bits of each program word. It can only read the lowest
 * 8-bits. We need to use the built-in flash access routines to get access to
 * all 14-bits in each word.
 * 
 * Due to the limitation of PIC xc8, these packed arrays cannot be represented
 * directly in C. An ASM include sets up all of these words. This include can
 * be generated with the tools/pack_strings.c program.
 */
void print_packed(const char *ptr)
{
    unsigned char buf;
    
    /* The CFGS bit should already be cleared from hardware */
    PMCON1 &= ~(_PMCON1_CFGS_MASK);
    PMADR = ptr;

    do {
        PMCON1bits.RD = 1;
        /* Two dummy operations as required by the flash program read process.
         * RD is not clearable by software, using a NOP can cause the compiler
         * to pop out extra instructions to guard inline ASM commands. Therefore
         * clearing the RD command does nothing but waste time, but not too much
         * time.
         */
        PMCON1bits.RD = 0;
        PMCON1bits.RD = 0;
        
        /* Read high byte first! */
        buf = ((PMDAT >> 7) & 0x7F);
        putch(buf);
        buf = (PMDAT & 0x7F);
        putch(buf);

        /* Increment flash pointer */
        PMADR++;
    } while (buf);
}

/* Clear the terminal
 * Uses VT100 commands to scroll the screen and put the cursor @ home.
 * This helps to hide the "Seed:" output in the terminal and works on at least
 * PuTTY and picocom.
 */
void clr_term(void) {
    putch(0x1B);
    putch('[');
    putch('2');
    putch('J');
    putch(0x1B);
    putch('[');
    putch('H');
}

/* Cleans the terminal, prints the intro text for the next stage, and generates
 * the PIN for the next stage.
 */
void print_stage(uint8_t stage)
{
    clr_term();
    print_packed(stage_text[stage]);
    generate_pin();
}

int main() {
    uint8_t recvcnt;
    uint8_t i;
    volatile uint8_t seed_volatile;

    stage = 0;
    pincnt = 0;
    recvcnt = 0;
    
    init_pic();
    init_uart();
    init_adc();
    init_timer0();

    stage_text[0] = stage_0_text;
    stage_text[1] = stage_1_text;
    stage_text[2] = stage_2_text;
    stage_text[3] = stage_3_text;
    stage_text[4] = completed_text;
    
    // Enable serial RX and general interrupts
    RCSTAbits.CREN = 1;
    INTCONbits.GIE = 1;
    INTCONbits.PEIE = 1;

    /* Enable the receive interrupt, expect spurious data, immediately clear
     * UART flags. If there are multiple characters received that are valid,
     * then the ISR should keep firing until the RX FIFO is clear, and then
     * return. At that point, clear both of the associated flags, and then
     * start our main loop.
     */
    PIE1bits.RCIE = 1;
    uart_flag = 0;
    newline_flag = 0;
    
    /* Clear the terminal, print the intro text, and wait for a newline.
     * This newline is our delay for setting the PRNG seed. Once a newline is
     * caught, the seed is set from TMR0 which is running at ~8.2 ms and is an
     * 8-bit quantity.
     * 
     * A seed of 0x00 is bad as it means all mutations after it will also be
     * 0x00. Add 1 in this case. This does mean that there are 255 seed values,
     * two of them are technically repeated, and there will only ever be 255
     * PIN values as a PIN of 0000 will never happen.
     */
    clr_term();
    print_packed(intro_text);
    while(!newline_flag);
    newline_flag = 0;
    seed = TMR0;
    if (!seed) seed++;
    
    /* Doing this and printing the seed in binary vs using printf to formate
     * saves about 220 words overall.
     */
    seed_volatile = seed;
    putch('S');
    putch('e');
    putch('e');
    putch('d');
    putch(':');
    putch(' ');
    for (i = 0; i < 8; i++) {
        seed_volatile = seed_volatile << 1;
        putch(CARRY + 0x30);
    }

    print_stage(0);
    
    while (1) {
#if UART
        if (uart_flag) {
#ifdef ECHO_UART
            putch(uart_byte);
#endif
            uart_flag = 0;
            if(recvcnt != 8) cmdstring[recvcnt++] = uart_byte;
        }
#endif
        
        if (adc_flag) {
            adc_flag = 0;

            /* Check to see if a new valid button press was received. 
             * Since stage 0 is awkward and really naive, we need to compare
             * at every change. No matter the stage, the kpcnt would only ever
             * increase by 1 if a new byte came in. This new byte has already
             * been added to the buffer.
             * The only thing thats really different, is stage 0 when
             * kpcnt is less than 4.
             * Once kpcnt == 4, then stage 0 behaves exactly the same as
             * stage 1 in terms of timing. However its still only comparing a
             * single digit at a time as it comes in.
             */
            
            /* if a valid input was detected from adc_parse, increment the
             * current pin counter. The valid digit has already been placed in
             * the pin_input[] array thanks to adc_parse().
             * 
             * NOTE: This section needs to be nested like this!
             * This allows stage 0 to call kp_compare ONLY when a new PIN digit
             * was read in!
             */
            if (adc_parse()) {
                pincnt++;
                /* ADC/UART interrupts do not _need_ to be disabled here. This
                 * stage can be visually watched to determine the correct PIN.
                 */
                if (stage == 0 && pincnt < 4) {
                    if (!kp_compare()) {
                        led_flicker(LED_R);
                        pincnt = 0;
                    }
                }
            }

            if (pincnt == 4) {
                /* Disable UART and ADC interrupts during the compare routines
                 * to not allow them to throw off the timing.
                 */
                PIE1bits.ADIE = 0;
                PIE1bits.RCIE = 0;
                
                if (kp_compare()) {
                    led_toggle(LED_G);
                    __delay_ms(2000);
                    led_toggle(LED_G);
                    stage++;
                    print_stage(stage);
                } else {
                    led_flicker(LED_R);
                }
                
                /* Clear our the pin_input buffer and re-enable ADC/UART RX */
                while (--pincnt) pin_input[pincnt] = 0;
                
                PIR1bits.RCIF = 0;
                PIE1bits.RCIE = 1;
                
                PIR1bits.ADIF = 0;
                PIE1bits.ADIE = 1;
            }
        }
#if UART
        if (newline_flag) {
            /* Clean up buffer and reset for next command */
            newline_flag = 0;
            while(recvcnt) cmdstring[--recvcnt] = 0;
        }
#endif
    }
    return (EXIT_SUCCESS);
}

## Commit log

2019-06-20 Initial commit of files for safe keeping
    Schematic is mostly done, pending final review
    Layout is still WIP
    Datasheet PDFs added for ICs
    [HHV_SCA_Demo-P1.brd, HHV_SCA_Demo-P1.sch]
2019-07-30 eagle: Final draft of P1 rev
    [HHV_SCA_Demo-P1.brd, HHV_SCA_Demo-P1.sch]
2019-07-30 eagle: Added OSHPark design rule file
    Has been slightly modified to round pads, tent vias, set pin 1 TH
    to square, increase isolation
2019-07-30 eagle: Finalized schematic and board files
    Added donation text to back silkscreen
    Changed schematic names of S* to SW*
    Removed value from SW5
    Added color values to D*
    [HHV_SCA_Demo-P1.brd, HHV_SCA_Demo-P1.sch]
2019-07-30 eagle: out: Added gerber files, named with OSHPark extensions
    Added Gerbv project file
    [HHV_SCA_Demo-P1.gbl, HHV_SCA_Demo-P1.gbo, HHV_SCA_Demo-P1.gbs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]
2019-07-30 eagle: Added BOM
2019-07-30 docs: Added PCB top and bottom photos
    Derived from OSHPark's automatic tools
2019-08-28 docs: writeup: Moved to README
    Cleaned up formatting of asm
    Updated with good Stage 2 text
    Added photos for Stage 1
2019-08-28 docs: Added photos of Stage 1 captures
    Pulseview window capture of a correct and incorrect first digit
2019-08-29 README: Added notes, also info about PCB files
    Added observational note about Saleae clones working better with pulseview
    Added information about building a copy of the whole device
2020-02-16 docs: README: Updated content
    Clarified stage 2 nop workaround and why
    Updated code to reflect the optimizations made for stage 3
